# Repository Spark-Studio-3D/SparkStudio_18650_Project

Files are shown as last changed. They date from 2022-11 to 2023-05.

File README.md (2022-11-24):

# SparkStudio_18650_Project

This OpenSCAD file renders .stl files for Mike Nolley's 18650 based USB charger project at Spark Studio Salem <https://sparkstudiosalem.com/>.

The box accomodates an IP5328 charge management board available from:

<https://www.aliexpress.us/item/3256801127506668.html>

<https://www.ebay.com/itm/193381612879>

...as well as many other vendors on EBay and AliExpress.

Sadly, the manufcturer's name and part number are not in evidence.  Match this image for positive identification:

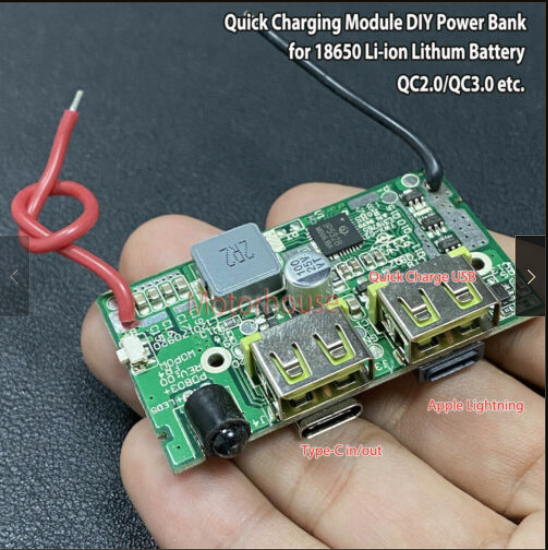
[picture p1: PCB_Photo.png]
PCB Image


This box can be configured for any number of 18650 cells up to the size limits of
your 3d printer.

The BOSL2 Library is required for this project.  <https://github.com/revarbat/BOSL2>

The SCAD Customizer can be used to set the following variables:

+ part  - The part to be rendered. Possible parts are box, lid, button, window, & test.
        The "test" part is the pcb end of the box to verify that parts printed on a
        particular printer will fit the pcb snugly.

+ battery_count - The number of 18650's the box is intended to hold.  Typically 4 or 6.

+ buffer - The buffer space around each battery for flame-suppressing buffer filler.

+ wall - The box wall thickness. Typically 2mm.

+ corner - The radius of the corner rounding on the outside of the box.

+ iwall_fudge - A fudge factor to adjust the box for a snug fit of the pcb, Initially 1.25.
              Decrease it for a tighter fit, increase it to loosen the fit.

With the exception of the window, parts can be printed with any available filament.
The window must be printed with transparent filament.
Use:

+ 4 perimeters
+ ZERO infill
+ ZERO bottom layers
+ 4 top layers with a rectilinear top fill pattern.

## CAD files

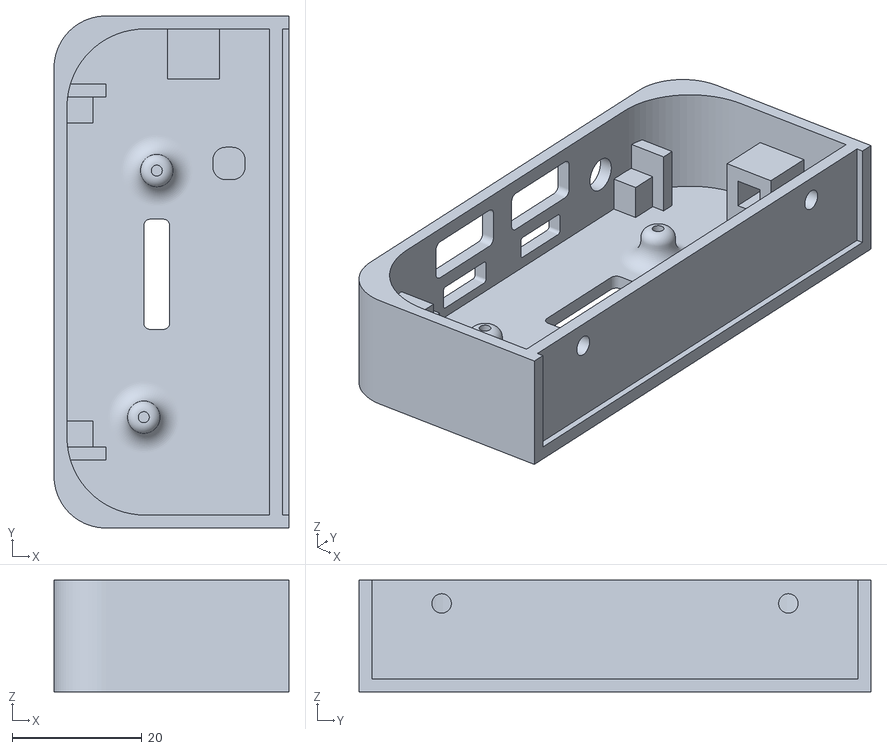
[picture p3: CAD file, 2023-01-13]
Test.stl
36.2 x 79.0 x 17.2

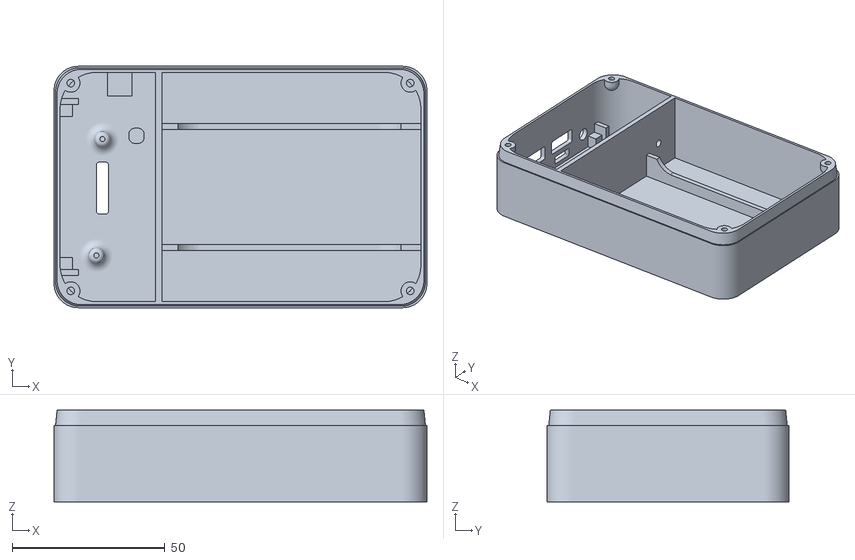
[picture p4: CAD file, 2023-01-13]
Box-4WW.stl
122.0 x 79.0 x 30.0

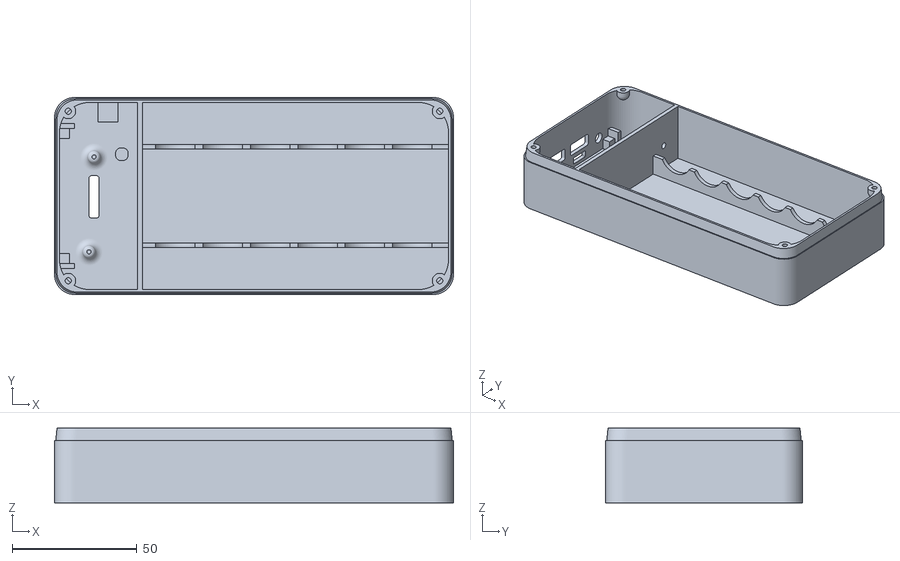
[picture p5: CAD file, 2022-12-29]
Box-6.stl
160.0 x 79.0 x 30.0

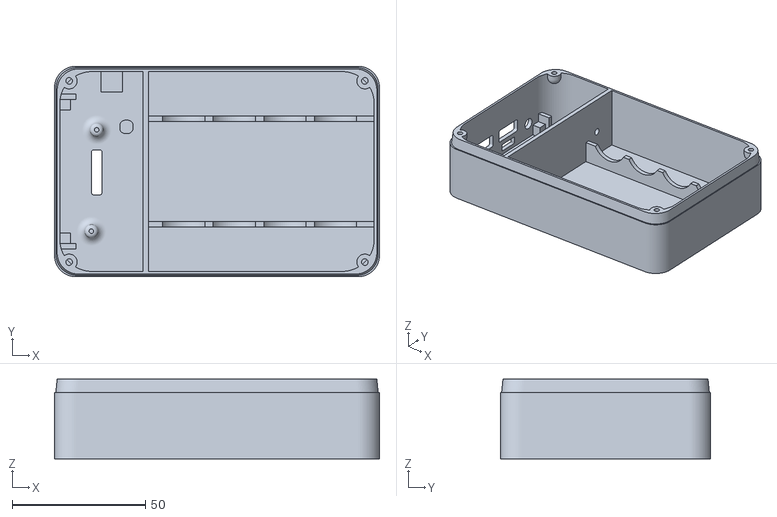
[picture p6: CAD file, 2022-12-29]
Box-4.stl
122.0 x 79.0 x 30.0

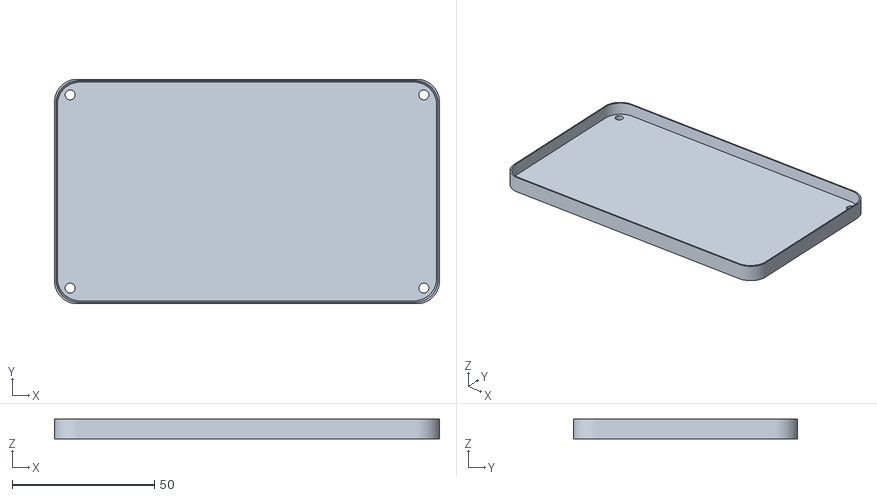
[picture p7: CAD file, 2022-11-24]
Lid-4.stl
135.5 x 79.0 x 7.00

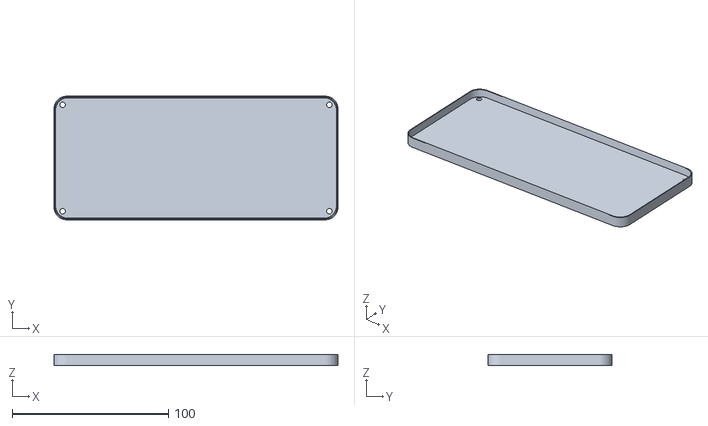
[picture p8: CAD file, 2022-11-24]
Lid-6.stl
181.5 x 79.0 x 7.00

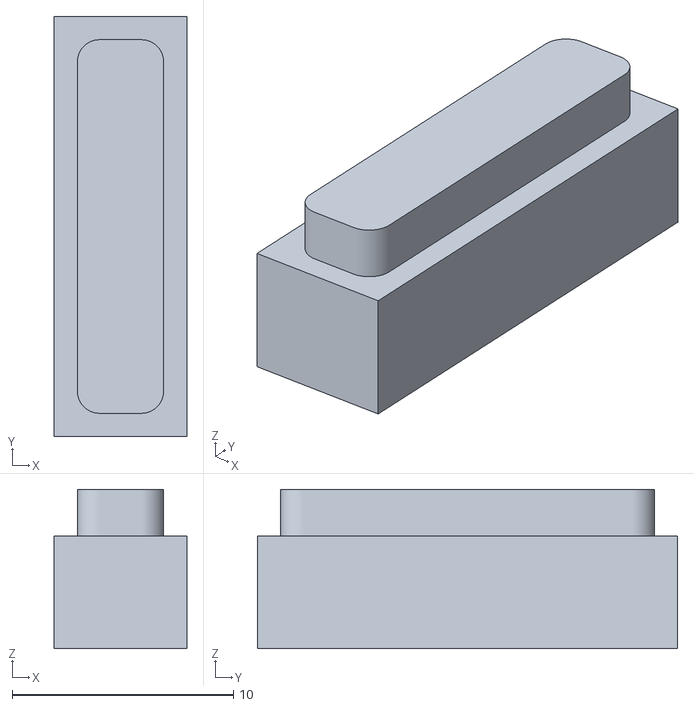
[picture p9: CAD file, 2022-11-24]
Window.stl
6.00 x 19.0 x 7.20

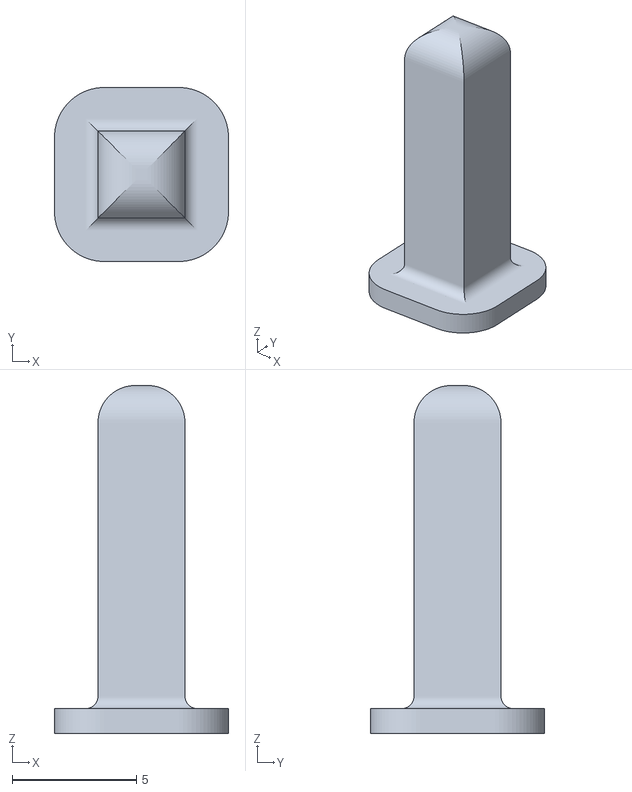
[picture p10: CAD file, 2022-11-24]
Button.stl
7.00 x 7.00 x 14.0

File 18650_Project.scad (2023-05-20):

/* ***************************************************************************** *\
   18650_Project.scad
	-----------------------------------------------------------------------------

	Developed by:			Richard A. Milewski
	Description:            
   	

	Version:                1.0
	Creation Date:          10 Nov 2022
	Modification Date:      21 Jan 2023
	Email:                  richard+spark@milewski.org
	Copyright 				©2022 by Richard A. Milewski
    License                 Mozilla Public License v2.0

\* ***************************************************************************** */


/* ***************************************************************************** *\
    
    NOTES

    The variable iwall_fudge may need to be adjusted to account for printer
    over or under extrusion. It should be set to provide a snug fit for the pcb.
    Decrease it for a tighter fit, increase it to loosen the fit.

\* ***************************************************************************** */

/* ***************************************************************************** *\
    
    CONFIGURATION

\* ***************************************************************************** */
include <BOSL2/std.scad>

part = "box";       // [box, lid, button, window, test]
// Add Charging Indication Window
window = true;      // [true, false]

// Battery Type
batt_type = "other";   // [18650, other]
// Batteries are spot welded together  
welded = false;     // [true, false]  

// Show phantom PCB
phPCB = false;    // [true, false]
// Show phantom batteries
phBat = false;  // [true, false]


battery_count = 4;
battery_spacing = 1;
buffer = 5;
wall = 2;
corner = 8;
iwall_fudge = 1.25;

module hide_variables () {}  // variables below hidden from Customizer

$fn = 72;
epsilon = 0.1 ;

2buffer = buffer*2;
battery = [18, 65, 18];
pcb = [30, 53.5, 1.3];
pcb_box = [30, 54, 11.4];

floor = wall;

icorner = corner - wall;
icorner2 = 1.5 * corner;      //Non std value to make fillet for screw post

battery_space = [(battery_count * (battery.x + battery_spacing)) + buffer * 2, battery.y + 2 * buffer, battery.z + buffer];
ibox = [pcb.x + wall + battery_space.x, battery_space.y, battery_space.z];
battery_center = [ibox.x/2 - battery_space.x/2, 0, buffer + battery.z/2];
box = [ibox.x + wall * 2, ibox.y + wall * 2, ibox.z];
stacker = [box.x, box.y, buffer];

screw_post = [6, undef, stacker.z]; // post_dia, undef, post.z
screw_spacing = [ibox.x - wall - 5, ibox.y - wall - 5];
screw_hole = 2.5; //dia

// Key Locations
pcb_lift = floor + 3; 
internal_wall_loc = [-ibox.x/2 + pcb.x + wall/2 + iwall_fudge, 0, floor]; 
pcb_center = [-ibox.x/2 + pcb.x/2, 0, floor + pcb_lift + pcb.z/2];
pcb_ctr_left = pcb_center + [-pcb.x/2 , 0, 0];
pcb_back_left = pcb_ctr_left + [0, pcb.y/2, 0];
pcb_back_left_floor = pcb_back_left + [0, 0, -(pcb_lift + pcb.z/2)];
pcb_front_left = pcb_ctr_left + [0, -pcb.y/2, 0];
pcb_front_left_floor = pcb_front_left + [0, 0, -(pcb_lift + pcb.z/2)];
pcb_top = pcb_center + [0, 0, pcb.z/2];
pcb_bot = pcb_center + [0, 0, -pcb.z/2];

pcb_hole = 1.7;
pcb_post = [5, undef, pcb_lift]; // d, undef, l
pcb_post_rounding = [-3, 1.5];     // rounding1, rounding2
pcb_front_post_loc = pcb_front_left_floor + [11 + pcb_hole/2, 3.5 + pcb_hole/2, 0];
pcb_back_post_loc = pcb_back_left_floor + [13 + pcb_hole/2, -(10.25 + pcb_hole/2), 0];

pcb_support = [4, 4.5, pcb_lift];
pcb_front_support_loc = pcb_front_left_floor + [2,  1.5, 0];
pcb_back_support_loc  = pcb_back_left_floor  + [2, -1.5, 0];
pcb_right_support = [ 5, 5, pcb_lift]; 
pcb_right_support_loc = pcb_back_left_floor  + [pcb.x - 5, -10, 0]; 

pcb_stop = [8, 2, pcb_lift + 4];
pcb_front_stop_loc = pcb_front_left_floor + [2, -1.25, 0];
pcb_back_stop_loc  = pcb_back_left_floor  + [2,  1.25, 0];



// Hole sizes and positions  
// usbC and lightning connectors centered under usbA connectors
led = [11, 5, 5];
led_loc = pcb_back_left + [0, -6.85, led.z/2 - 1];
led2 = [4, 17, floor + 2 * epsilon];
led2_loc = pcb_back_post_loc + [0, -(led2.y/2 + 7.5), -floor - epsilon ]; 

usbA = [10.2, 13.5, 6];
usbAlift = 1.44; //connector height above pcb
usbA_loc1 =  pcb_back_left + [0, -14.25 - usbA.y/2, usbA.z/2 + usbAlift];
usbA_loc2 =  pcb_front_left + [0, 8 + usbA.y/2, usbA.z/2 + usbAlift];

usbC = [7.5, 9.2, 3.3];
usbC_loc =  [usbA_loc1.x, usbA_loc1.y , pcb_bot.z - usbC.z/2]; 

lightning = [8.73, 10, 3.5];
lightning_loc = [usbA_loc2.x, usbA_loc2.y, pcb_bot.z - lightning.z/2]; 

buttonhole = [4, 6, 4];
buttonhole_loc = [-ibox.x/2 + 19.5, ibox.y/2, pcb_center.z];
button = [3.5, 3.5, 6.5];  // button.z is doubled in the button() module. 
button_support = [8, 8, pcb_lift + 5];
button_support_loc = [-ibox.x/2 + 19.5, pcb_back_left.y + 7, floor];
button_channel = [4.1, 12, 4.1];
button_channel_loc = button_support_loc + [0, 0, pcb_lift - pcb.z] ;



/* ***************************************************************************** *\
    
    Main

\* ***************************************************************************** */
if(part == "box") {
    box();
}

if(part == "button") {
    button();
}

if(part == "lid") {
   lid();
}

if(part == "window") {
   window();
}

if(part == "test") {
    left_half(s = 200, x = internal_wall_loc.x + 2)
    bottom_half(s = 200, z = box.z * .75)
    box();
}


/* ***************************************************************************** *\
    
    Modules

\* ***************************************************************************** */


module box() {
    color_this("lightgrey") shell();
    internal_wall();
    if(part != "test" && batt_type != "other") #battery_bay();
    color_this("dodgerblue") stacker_with_posts(true);
    if($preview && part != "test" && phPCB) pcb();
}

module button() {
    cuboid([button.x * 2, button.x * 2, 1], rounding = 2, edges = "Z", anchor = BOT);
    up(1) cuboid(button, rounding = -0.5, edges = BOT, anchor = BOT);
     up(1 + button.z) cuboid(button, rounding = 1.5, edges = TOP, anchor = BOT);
}

module floor() {
    cuboid([box.x, box.y, floor], rounding = corner, edges = "Z", anchor = BOT);
}

module shell() {
    difference() {
        union() {
            floor();
            up(floor) rect_tube(h = box.z, size = [box.x, box.y], 
                wall = wall, rounding = corner, irounding = icorner2, anchor = BOT);
        }
        //shell holes
        union() {
            color_this("red") {
                move(led_loc) xcyl(d = led.z, l = led.x);
                if(window) {
                    move(led2_loc)  cuboid(led2, rounding = 1,  edges = "Z", anchor = BOT);
                }
                move(buttonhole_loc) cuboid(buttonhole, rounding = 1, edges = "Y");           
                move(usbA_loc1) cuboid(usbA, rounding = 1,   edges = "X");
                move(usbA_loc2) cuboid(usbA, rounding = 1,   edges = "X");
                move(usbC_loc)  cuboid(usbC, rounding = 0.5, edges = "X");
                move(lightning_loc) cuboid(lightning, rounding = 0.5, edges = "X");
            }
        }
    }
    color_this("dodgerblue") {
        difference() {
            union () {
                move (pcb_front_post_loc) 
                    cyl(h = pcb_post.z, d = pcb_post.x, rounding1 = pcb_post_rounding.x,
                        rounding2 = pcb_post_rounding.y, anchor = BOT);
                move (pcb_back_post_loc)  
                    cyl(h = pcb_post.z, d = pcb_post.x, rounding1 = pcb_post_rounding.x,
                        rounding2 = pcb_post_rounding.y, anchor = BOT);
                }
            union() {
                move(pcb_back_post_loc) cyl(h=pcb_post.z, d = pcb_hole, anchor = BOT);
                move(pcb_front_post_loc) cyl(h=pcb_post.z, d = pcb_hole, anchor = BOT);
            }
        }
        move (pcb_front_support_loc) cuboid(pcb_support, anchor = BOT);
        move (pcb_back_support_loc)  cuboid(pcb_support, anchor = BOT);
        move (pcb_right_support_loc) cuboid(pcb_right_support, rounding = 2, edges = "Z", anchor = BOT);
        
        move (pcb_front_stop_loc) cuboid(pcb_stop, anchor = BOT);
        move (pcb_back_stop_loc)  cuboid(pcb_stop, anchor = BOT);

        difference() {
            move (button_support_loc) cuboid(button_support, anchor = BOT);
            move (button_channel_loc) color_this("red") cuboid(button_channel, anchor = BOT);
        }
    }
}

module lid() {
    difference () {
        floor();
        grid_copies(n = 2, spacing = screw_spacing)
            cyl(h = screw_post.z, d = screw_hole + 1, anchor = BOT);
    } 
    up(floor) stacker(false);
}

module battery() {
    ycyl(d = battery.x,  l = battery.y);
}
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

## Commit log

2022-11-14 Create 18650_Project.scad
    Added scad file
    [18650_Project.scad]
2022-11-14 Comment Correctoins
    Added date and fixed license reference.
    [18650_Project.scad]
2022-11-18 Added connector holes
    STL files not necessarily current.
    [18650_Project.scad, 18650_Project_Box_6.stl, 18650_Project_Lid_4.stl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]
2022-11-19 Adjusted hole positions
    Adjusted connector hole positions.
    [18650_Project.scad, 18650_Project_Box_6.stl, 18650_Project_Lid_4.stl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]
2022-11-19 Refactor
    Refactored post & hole locations
    [18650_Project.scad, 18650_Project_Test.stl]
2022-11-21 Added LED2 Window
    Added LED2 Window
    [18650_Project.scad, 18650_Project_Test.stl]
2022-11-21 Added button Support Channel
    Added Button Support Channel
    [18650_Project.scad, 18650_Project_Button.stl, 18650_Project_Test.stl]
2022-11-23 Window & Readme Update
    Window & Readme Update
    [18650_Project.scad, 18650_Project_Box-4.stl, 18650_Project_Button.stl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]
2022-11-23 Updated Readme & Photo
    Updated Readme & Photo
    [18650_Project.scad, 18650_Project_Lid-4.stl]
2022-11-24 Re=Rendered STLs
    Re-Rendered STLs
    [18650_Project_Box-4.stl, 18650_Project_Box-6.stl, 18650_Project_Button.stl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]
2022-11-24 Removed Debug Aids
    [18650_Project.scad]
2022-11-24 Re-rendered .STLs
    [Box-4.stl, Box-6.stl, Button.stl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]
2022-12-17 Reworked Battery Spacing
    Added battery-spacing parameter separate from buffer.
    Added customizer toggle for led2 window.
    [18650_Project.scad]
2022-12-17 Changed Battery Spacing
    Reduced to 0.4 mm
    [18650_Project.scad]
2022-12-17 Relocated USB Holes
    [18650_Project.scad]
2022-12-29 Tweaked USB Locations
    ...and modified support for spot-welded battery packs.
    [18650_Project.scad, Box-4.stl, Box-6.stl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]
2022-12-29 Revert "Changed Battery Spacing"
    This reverts commit 96c64849a74b15e514234b34a52f3fb452427fba.
    [18650_Project.scad]
2022-12-29 Fixed Mod Date
    [18650_Project.scad]
2023-01-13 Button conditional on Window
    Remove button hole and button suppoart if window is turned off.
    [18650_Project.scad, Box-4WW.stl, Test.stl]
2023-02-18 Window dependencies
    [18650_Project.scad]
2023-05-20 Added battery type option
    [18650_Project.scad]
